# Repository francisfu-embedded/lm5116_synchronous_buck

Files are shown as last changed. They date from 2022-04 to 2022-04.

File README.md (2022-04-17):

# lm5116_synchronous_buck
a 72W synchronous buck converter based on TI LM5116

- Features:
Input voltage range from 15 - 50V
Output Voltage: 12V    +- 2.5%
Output Current: Max 6A. Shuts off after reaching the limit
Max efficiency 96% at full load

- Notes:
The inductor of this buck converter circuit is changed from a 22u vishay smd inductor to a 97u toroidal inductor due to excessive inductor heating at no load.
The suspected reason is the inductor current spiking at light load DCM. 
Replacing with higher inductance solves the issue in the design as it decreases the output load "boundary" to CCM
Further investigations on this behaviour still needed!

- Remaining issues:
1. The current design has bad "acoustics". Inductor buzzing is audible. It is normal to have a buzzing noise in a switching converter prototype but it's still not
desirable. Further investigations needed on how to reduce this audible noise in a mature product.

2. After loading the converter and then returning back to no load, the buck converter still draws around 2.1W standby power - which is not seen when the circuit is first
powered up. Further inverstigations needed on this high standby power. It may have to do with the ic itself not in "standby" mode and / or the inductor current spiking
at no load

- Potential applications:
This project is a prototype design using TI's LM5116 and may open up more design ideas involving this chip. For instance, a fan driver or an AA battery charger.
The feedback voltage can be made programmable easily by attaching a filtered-pwm / DAC / pull-down resistors to the feedback pin, thus enabling voltage programming
or even current regulation using an external control loop (e.g. using an MCU). This control scheme is suitable for chargers and variable power supply. Related project 
maybe added to the github in the future.

- Thanks:
Big shout-outs to TI's engineers for their great documentation of the IC and their reference designs

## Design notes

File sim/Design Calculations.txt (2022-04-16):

Design Requirements of lm5116 wide input range synchronous buck converter

Author: Yuqi Fu

Input: 15 - 60V

Standard Operational Output: 12V
			     max 6A
		
Topology:
synchronous buck, current mode control, ccm 

Chip: LM5116

1.Switching Frequency:
	fs = 250k -  making Rt = 12.5 KOhm

2.Max Duty Cycle
	Assuming an efficiency of 90%
	D_max = V_out/(V_in_max * eta) = 0.222
	
3.Inductor Selection
	Select the current ripple to be delta_I = 0.3 * I_out  = 0.3 * 6= 1.8 A
    L = D_max * (V_in_max - V_out) / (delta_I * fs) = 0.222 (60 - 12) / (1.8 * 250000) = 23.7uH
	will use 22uH
	
4. Diode Selection
	synchronous buck, no diode used

5. Current Sense resistor
	since Vccx is not used
	Rs <= Vcs / (I_out + Vout * T / L) = 0.013444 ohm
	will use 0.013 ohm

6. Ramp Capacitor & Resistor
	Optimal current slope = Ios = Vout / 3 * 10 uA/V = 40uA

	C_ramp = (Ios * L) / (A * Rs * Vout) = (40 * e-6 * 22 * e-6) / (10 * 0.013 * 12) = 564pF
	will use 560pF, which is the nearest standard value

	Nominal input voltage is 30V
	Thus Vr = Vout/Vin * ((Vin-Vout) * gm + Ios)*T/C_ramp = 0.371V
	  
	R_ramp = (Vcc - Vr) / (Ios - 25uA) = 468571 Ohm
	take 470k ohm

7. Output Capacitor Selection
	Ignoring ESR and only considering ripple voltage due to capacitor
	Considering steady state operation:
		I want ripple to be delta_V_out = 0.003V
		C_out = delat_I / (8*f*delta_V_out) = 0.3 * 6 / (8 * 250k * 0.005) = 180uF
		
	Considering transient states. assumming a output current change of 6A, with desired overshoot voltage = 0.5V
	C_out_os = delta_I_out^2 * L / (2 * V_out * V_os) = 66uF

	I will use 5x47uF MLCCs for the application
	Max ESR of each is 0.00169 Ohm

8. Input Capactitor Selection
	take a Vin_pp = 1V, D = 0.5 (for maximum value of D(1-D))
	Cin >= D*(1-D)*Iout/ (Vin_pp * fs) = 6uF
	4x2.2uF MLCCs will be used as input caps

9. Bulk Capacitor Selection
	Electrolytic caps are used for bulk capacitors
	Take D_max = 12/15 = 0.8 Vin_tran = 0.5V, I_stp = 6
	ESR requirement: ESR <= Vin_tran / (I_stp * D_max) = 0.104

	Assuming a control bandwith of 25kHz
	Tr_ps = 1/ (4 * 25k)  = 10us
	Cb >= 0.5 * I_stp * Dmax * Tr_ps / Vin_tram - Ce (1- Tolerance) = 0.5*6*0.8*10us/0.5 - 8.8(1-0.2)e-6 = 41uF
	Will use one 47uF electrolytic cap

10. VCC Capacitor Selection
	choose 1uF straight from reference design

11. Bootstrap Capacitor Selection
	1uF selected straight from reference design

12. Mosfet Selection
	Si7852, straight from reference design

13. Soft Start Capacitor Selection
	0.1uF selected straight from reference design

14. Feedback Resistor Divider
	R2 / R1 = 12/1.215 - 1 = 8.87
	choose R2 = 12k
	choose R1 = 1.3k

15: UVLO Network and Enable Pin
	choose R_uvlo2 = 100k
	R_uvlo1 = 1.215 * (R_uvlo2 / (V_in_min + 5uA * R_uvlo2  - 1.215)) = 8.5k
	take 9k
	Choose Cft = 1uF
	A 1M resistor is connected between enable pin and Vin

16: Snubber Network
	not used

17: Compensator Caps and Res
	R1 = 12k
	R2 = 62k
	C1 = 2n
	C2 = 5p

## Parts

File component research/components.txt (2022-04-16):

All prices are in CAD
	Product Details	Quantity	Availability	Unit Price	Extended Price
 1
553-4030-1-ND	
‎553-4030-1-ND‎
‎PA4343.223ANLT‎
Pulse Electronics Power
FIXED IND 22UH 8A 35 MOHM SMD
Customer Reference
2
Immediate
3.01000
$6.02
 2
P.013AVCT-ND	
‎P.013AVCT-ND‎
‎ERJ-8BWJR013V‎
Panasonic Electronic Components
RES 0.013 OHM 5% 1W 1206
Customer Reference
2
Immediate
1.03000
$2.06
 3
587-5192-1-ND	
‎587-5192-1-ND‎
‎QMK212SD561KD-T‎
Taiyo Yuden
CAP CER 560PF 250V 0805
Customer Reference
5
Immediate
0.41000
$2.05
 4
P470KACT-ND	
‎P470KACT-ND‎
‎ERJ-6GEYJ474V‎
Panasonic Electronic Components
RES SMD 470K OHM 5% 1/8W 0805
Customer Reference
10
Immediate
0.09300
$0.93
 5
478-1206YD476MAT2ACT-ND	
‎478-1206YD476MAT2ACT-ND‎
‎1206YD476MAT2A‎
KYOCERA AVX
CAP CER 47UF 16V 1206
Customer Reference
6
Immediate
2.59000
$15.54
 6
478-5719-1-ND	
‎478-5719-1-ND‎
‎08053C225KAT2A‎
KYOCERA AVX
CAP CER 2.2UF 25V X7R 0805
Customer Reference
10
Immediate
0.31800
$3.18
 7
445-173842-1-ND	
‎445-173842-1-ND‎
‎C2012X8R1C105M125AE‎
TDK Corporation
CAP CER 1UF 16V X8R 0805
Customer Reference
10
Immediate
0.43700
$4.37
 8
SI7850ADP-T1-GE3CT-ND	
‎SI7850ADP-T1-GE3CT-ND‎
‎SI7850ADP-T1-GE3‎
Vishay Siliconix
MOSFET N-CH 60V 10.3A/12A PPAK
Customer Reference
4
Immediate
1.83000
$7.32
 9
13-RE0805FRE0712KLCT-ND	
‎13-RE0805FRE0712KLCT-ND‎
‎RE0805FRE0712KL‎
YAGEO
RES SMD 12K OHM 1% 1/8W 0805
Customer Reference
10
Immediate
0.06800
$0.68
 10
738-RMCF0805JT1K30CT-ND	
‎738-RMCF0805JT1K30CT-ND‎
‎RMCF0805JT1K30‎
Stackpole Electronics Inc
RES 1.3K OHM 5% 1/8W 0805
Customer Reference
10
Immediate
0.02900
$0.29
 11
2019-RK73G2ATTD1003FCT-ND	
‎2019-RK73G2ATTD1003FCT-ND‎
‎RK73G2ATTD1003F‎
KOA Speer Electronics, Inc.
THICKFILM RESISTOR 0805
Customer Reference
5
Immediate
0.44000
$2.20
 12
13-RT0805BRE079KLCT-ND	
‎13-RT0805BRE079KLCT-ND‎
‎RT0805BRE079KL‎
YAGEO
RES SMD 9K OHM 0.1% 1/8W 0805
Customer Reference
10
Immediate
0.48000
$4.80
 13
478-5148-1-ND	
‎478-5148-1-ND‎
‎08051A0R5CAT2A‎
KYOCERA AVX
CAP CER 0.5PF 100V C0G/NP0 0805
Customer Reference
10
Immediate
0.17100
$1.71
 14
478-10509-1-ND	
‎478-10509-1-ND‎
‎08055A201JAT2A‎
KYOCERA AVX
CAP CER 200PF 50V NP0 0805
Customer Reference
10
Immediate
0.23900
$2.39
 15
541-RCS080562K0FKEACT-ND	
‎541-RCS080562K0FKEACT-ND‎
‎RCS080562K0FKEA‎
Vishay Dale
RES SMD 62K OHM 1% 0.4W 0805
Customer Reference
1
Immediate
0.38000
$0.38
 16
478-08055A5R0DAT2ACT-ND	
‎478-08055A5R0DAT2ACT-ND‎
‎08055A5R0DAT2A‎
KYOCERA AVX
CAP CER 5PF 50V NP0 0805
Customer Reference
1
Immediate
0.26000
$0.26
 17
311-4328-1-ND	
‎311-4328-1-ND‎
‎CC0805KRX7R9BB202‎
YAGEO
CAP CER 2000PF 50V X7R 0805
Customer Reference
5
Immediate
0.21000
$1.05
 18
LM5116MH-ND	
‎LM5116MH-ND‎
‎LM5116MH‎
Texas Instruments
IC REG CTRLR BUCK 20TSSOP
Customer Reference
2
Immediate
14.36000
$28.72
Subtotal $83.95
 Checkout
 Your data will be encrypted and transmitted securely.
Summary
Web ID:	325588698
Access ID:	57025
Subtotal:	$83.95
Incoterms:
DDP (Duty and customs paid by Digi-Key)
Cart Tools
Input
Add Carts - add previous carts
Add List - add an existing list
Add Quote - add previous quotes
Options
New Cart - create a new empty cart
Schedule Shipments - schedule your order for a future release
Delay Entire Order - select a future delivery date for this order
Resume Cart - resume a previous cart
Output
Download - save a copy of your cart in spreadsheet format
Cart Share - create a new cart including only the quantity, part number, and customer reference
Information:   Please refer to our Terms and Conditions a

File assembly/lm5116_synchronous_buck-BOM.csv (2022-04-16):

Comment | Designator | Footprint | LCSC
1u | C1,C11,C13 | Capacitor_SMD:C_0603_1608Metric
47u | C14,C15,C16,C17,C18 | Capacitor_SMD:C_1206_3216Metric
560p | C2 | Capacitor_SMD:C_0603_1608Metric
22n | C12,C20 | Capacitor_SMD:C_0603_1608Metric
5p | C3 | Capacitor_SMD:C_0603_1608Metric
47u | C4 | Capacitor_SMD:C_Elec_8x10.2
2n | C5 | Capacitor_SMD:C_0603_1608Metric
100n | C6,C19 | Capacitor_SMD:C_0603_1608Metric
2.2u | C7,C8,C9,C10 | Capacitor_SMD:C_1206_3216Metric
CMPD2003 | D1,D2,D3 | Diode_SMD:D_SOT-23_ANK
MountingHole_Pad | H1,H2,H3,H4 | MountingHole:MountingHole_4.5mm_Pad_Via
Conn_01x08_Female | J2 | Connector_PinHeader_2.54mm:PinHeader_1x08_P2.54mm_Vertical
22u | L1 | Inductor_SMD:L_12x12mm_H6mm
100k | R1 | Resistor_SMD:R_0603_1608Metric
12k | R10 | Resistor_SMD:R_0603_1608Metric
1.3k | R11 | Resistor_SMD:R_0603_1608Metric
10k | R2,R7 | Resistor_SMD:R_0603_1608Metric
62k | R3 | Resistor_SMD:R_0603_1608Metric
470k | R4 | Resistor_SMD:R_0603_1608Metric
12.4k | R5 | Resistor_SMD:R_0603_1608Metric
1M | R6 | Resistor_SMD:R_0603_1608Metric
2.2R | R8 | Resistor_SMD:R_0805_2012Metric
0.013R | R9 | Resistor_SMD:R_1206_3216Metric
LM5116NH | U1 | Package_SO:HTSSOP-20-1EP_4.4x6.5mm_P0.65mm_EP3.4x6.5mm
Si7850 | U2,U3 | Package_SO:PowerPAK_SO-8_Single

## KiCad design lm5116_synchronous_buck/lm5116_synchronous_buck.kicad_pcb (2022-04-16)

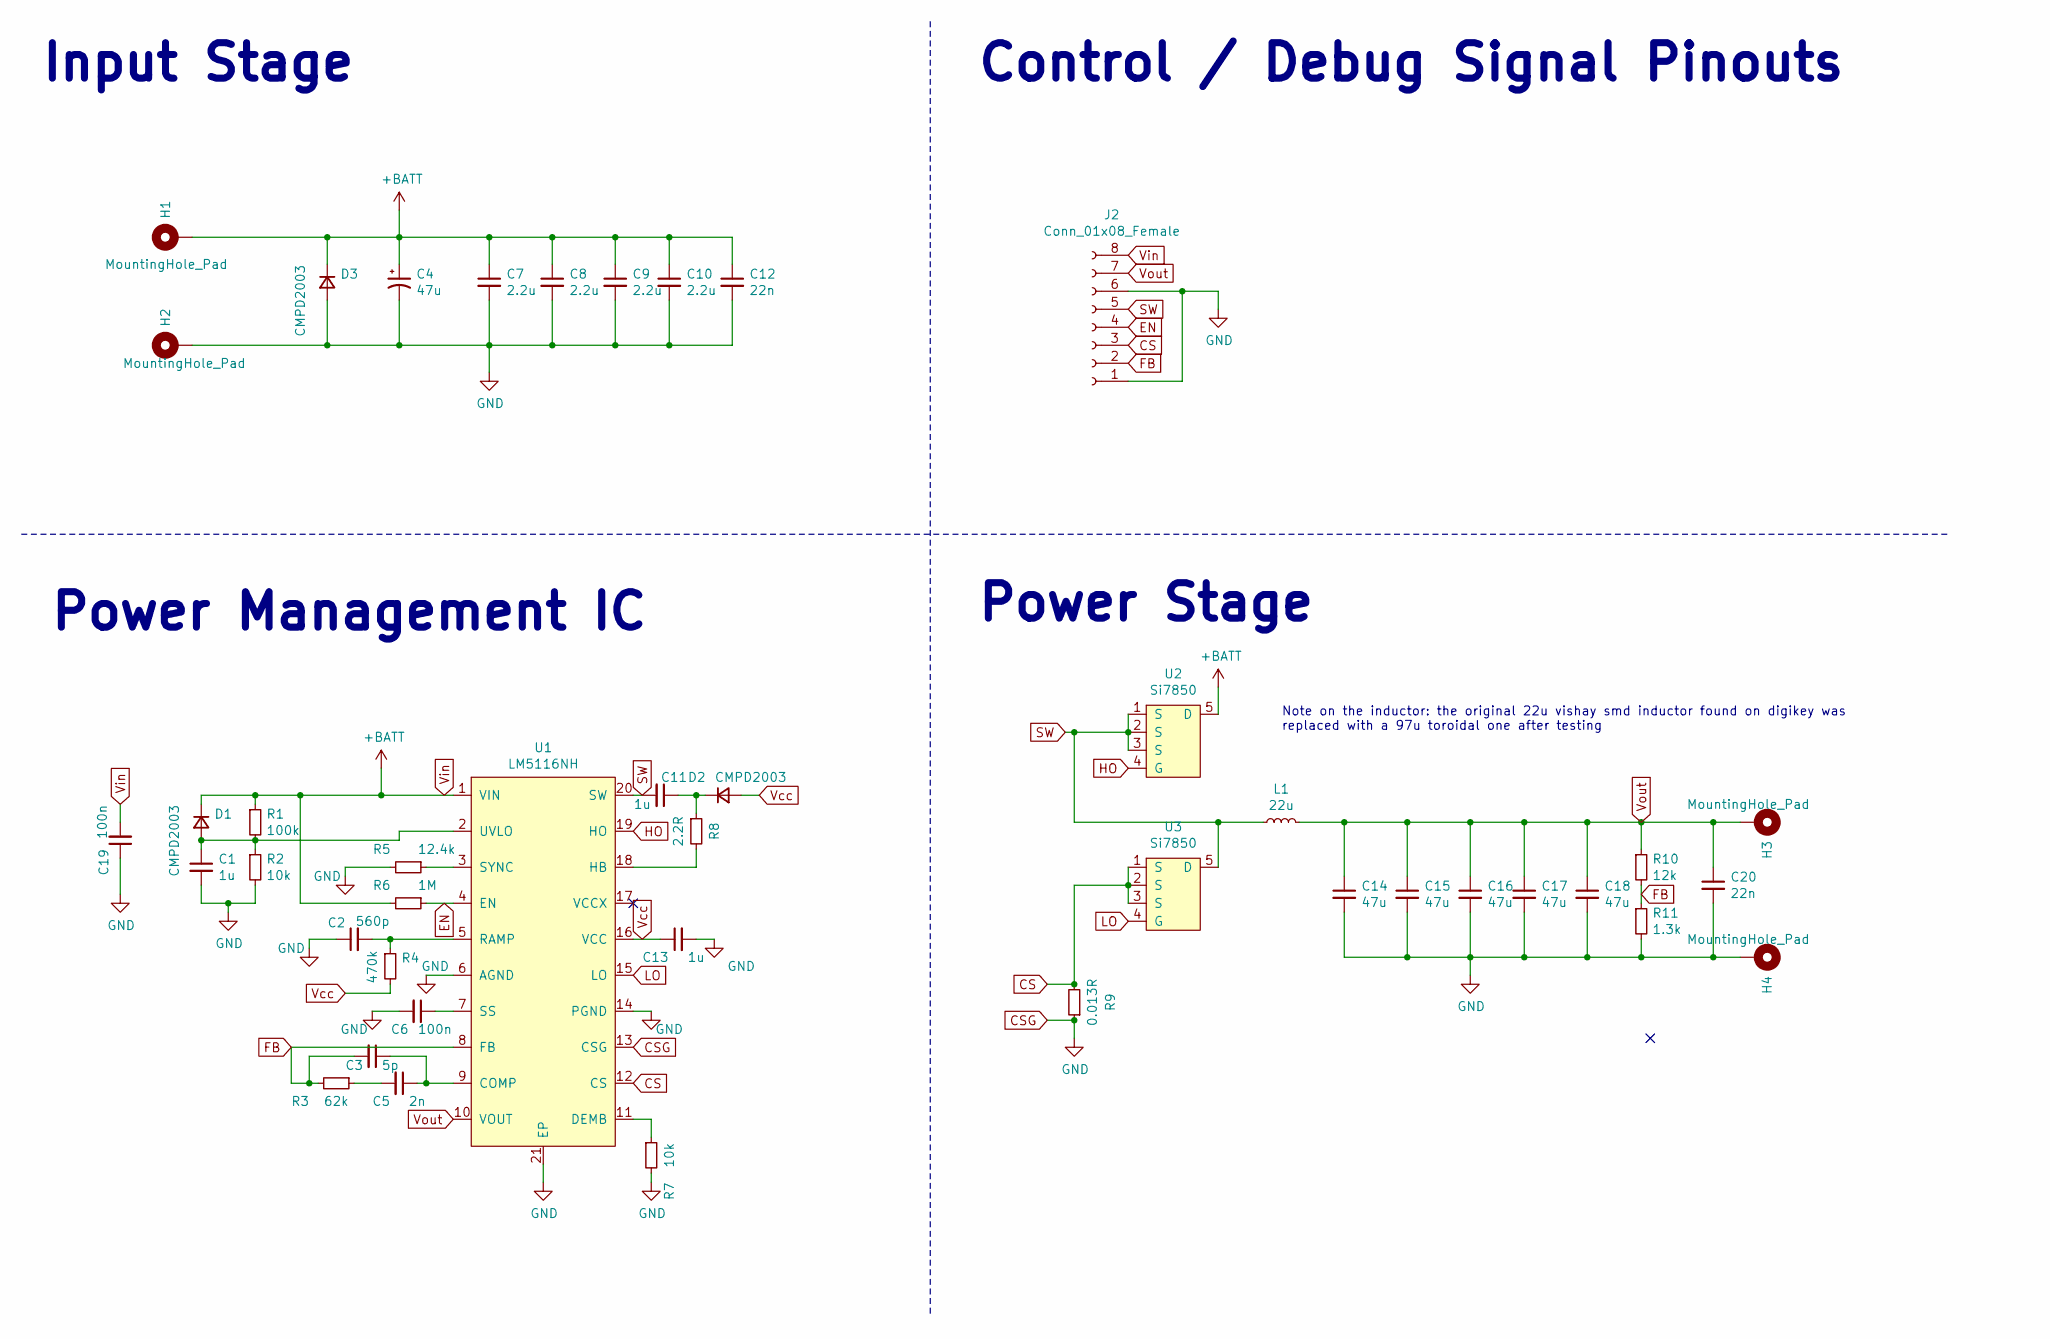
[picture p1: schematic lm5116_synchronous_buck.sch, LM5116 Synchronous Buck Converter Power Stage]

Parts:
C1, C11, C13: 1u; C_0603_1608Metric; LCSC Part # C90540
C2: 560p; C_0603_1608Metric; LCSC Part # C1627
C3: 5p; C_0603_1608Metric; LCSC Part # C1669
C4: 47u; C_Elec_8x10.2; LCSC Part # C336483
C5: 2n; C_0603_1608Metric; LCSC Part # C1604
C6, C19: 100n; C_0603_1608Metric; LCSC Part # C83054
C7, C8, C9, C10: 2.2u; C_1206_3216Metric; LCSC Part # C39619
C12, C20: 22n; C_0603_1608Metric; LCSC Part # C1697
C14, C15, C16, C17, C18: 47u; C_1206_3216Metric; LCSC Part # C30300
D1, D2, D3: CMPD2003; D_SOT-23_ANK
H1, H2, H3, H4: MountingHole_Pad; MountingHole_4.5mm_Pad_Via
J2: Conn_01x08_Female; PinHeader_1x08_P2.54mm_Vertical
L1: 22u; L_12x12mm_H6mm
R1: 100k; R_0603_1608Metric; LCSC Part # C25803
R2, R7: 10k; R_0603_1608Metric; LCSC Part # C269701
R3: 62k; R_0603_1608Metric; LCSC Part # C23221
R4: 470k; R_0603_1608Metric; LCSC Part # C25599
R5: 12.4k; R_0603_1608Metric; LCSC Part # C22865
R6: 1M; R_0603_1608Metric; LCSC Part # C22935
R8: 2.2R; R_0805_2012Metric
R9: 0.013R; R_1206_3216Metric; LCSC Part # C201279
R10: 12k; R_0603_1608Metric; LCSC Part # C269442
R11: 1.3k; R_0603_1608Metric; LCSC Part # C22767
U1: LM5116NH; HTSSOP-20-1EP_4.4x6.5mm_P0.65mm_EP3.4x6.5mm; LCSC Part # C13755
U2, U3: Si7850; PowerPAK_SO-8_Single

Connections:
CS: J2.3, R9.2, U1.12 (CS), U3.1 (S), U3.2 (S), U3.3 (S)
CSG: C1.2, C2.1, C4.2, C6.2, C7.2, C8.2, C9.2, C10.2, C12.2, C13.2, C14.2, C15.2, C16.2, C17.2, C18.2, C19.1, C20.2, D3.2 (A), H2.1, H4.1, J2.1, J2.6, R2.2, R5.2, R7.2, R9.1, R11.2, U1.6 (AGND), U1.13 (CSG), U1.14 (PGND), U1.21 (EP)
EN: J2.4, R6.1, U1.4 (EN)
FB: C3.2, J2.2, R3.2, R10.2, R11.1, U1.8 (FB)
HO: U1.19 (HO), U2.4 (G)
LO: U1.15 (LO), U3.4 (G)
unnamed: C1.1, D1.2 (A), R1.2, R2.1, U1.2 (UVLO)
unnamed: C2.2, R4.1, U1.5 (RAMP)
unnamed: C3.1, C5.1, U1.9 (COMP)
unnamed: C5.2, R3.1
unnamed: C6.1, U1.7 (SS)
unnamed: C11.1, D2.1 (K), R8.1
unnamed: R5.1, U1.3 (SYNC)
unnamed: R7.1, U1.11 (DEMB)
unnamed: R8.2, U1.18 (HB)
SW: C11.2, J2.5, L1.1, U1.20 (SW), U2.1 (S), U2.2 (S), U2.3 (S), U3.5 (D)
Vcc: C13.1, D2.2 (A), R4.2, U1.16 (VCC)
Vin: C4.1, C7.1, C8.1, C9.1, C10.1, C12.1, C19.2, D1.1 (K), D3.1 (K), H1.1, J2.8, R1.1, R6.2, U1.1 (VIN), U2.5 (D)
Vout: C14.1, C15.1, C16.1, C17.1, C18.1, C20.1, H3.1, J2.7, L1.2, R10.1, U1.10 (VOUT)

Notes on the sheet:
Input Stage
Control / Debug Signal Pinouts
Power Stage
Power Management IC
Note on the inductor: the original 22u vishay smd inductor found on digikey was replaced with a 97u toroidal one after testing

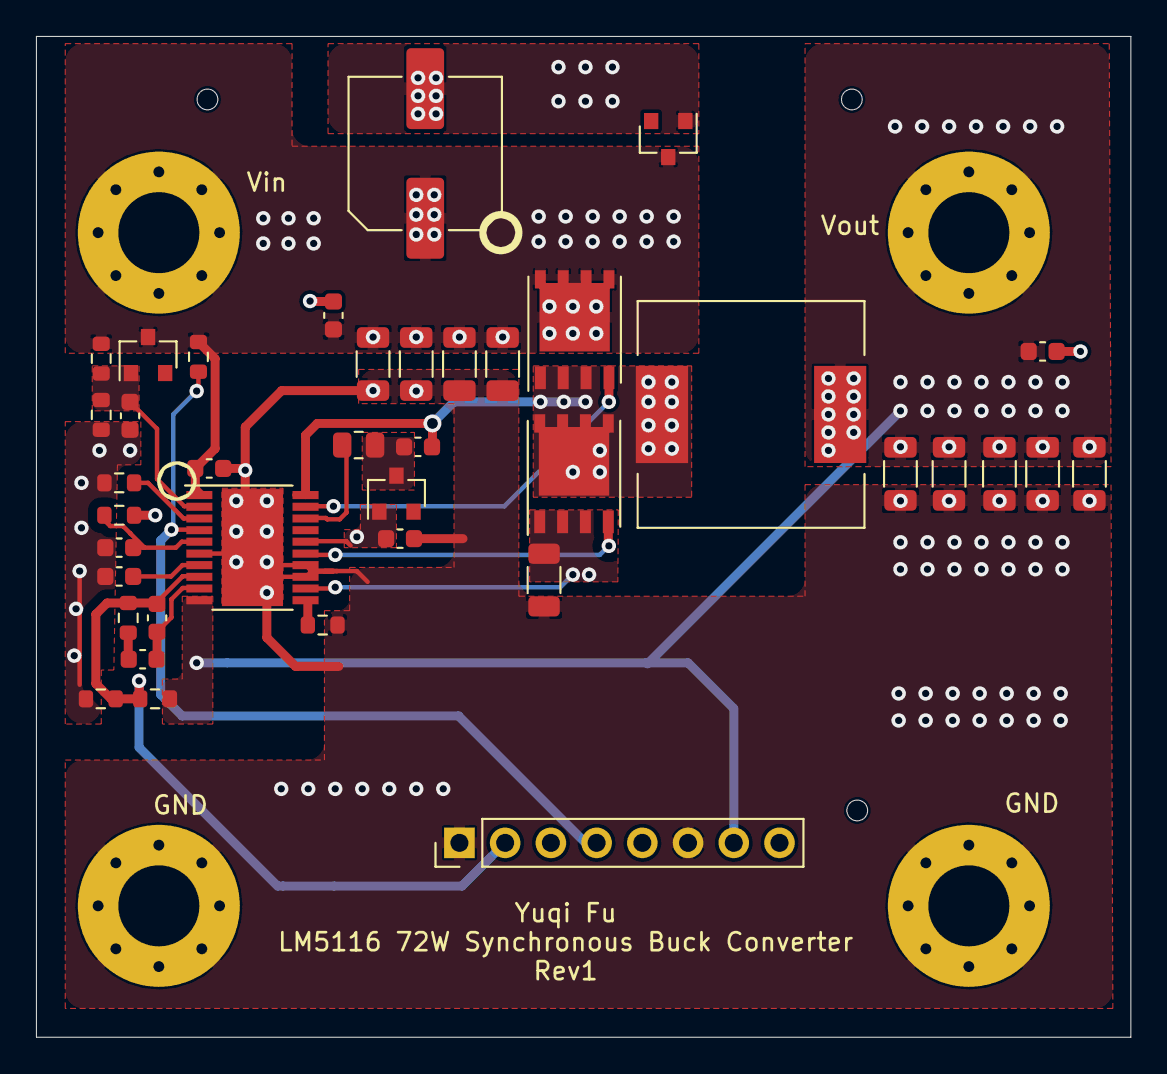
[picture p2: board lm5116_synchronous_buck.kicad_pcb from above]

Board: 4 copper layers, 60.8 x 55.6 mm, 43 parts (0 on the bottom side), 19 nets.
